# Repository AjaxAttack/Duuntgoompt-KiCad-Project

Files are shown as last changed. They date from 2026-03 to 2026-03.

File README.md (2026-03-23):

# Duuntgoompt-KiCad-Project
## This repo is the Duuntgoompt project files home.
### The Duuntgoompt PCB, with features:
- Esp32s3 based system
- Wifi & Bluetooth compatible
- USB C
- 1x26 Pin M Connections Suitable for breadboard plug-n-use
- Solder Bridge LED Indicators
- Qwiic I2C Connectors for other sensor modules
### Duuntgoompt - Blender Full Render
output gif fuuntboompt

### Duuntgoompt Overhead


### Top-level Schematic Image


### Power Schematic 


### Connectors Schematic


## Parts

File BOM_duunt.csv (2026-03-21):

Id | Designator | Footprint | Quantity | Designation | Supplier and ref
1 | U2 | SOT-89-3 | 1 | AZ1117C
2 | C10,C3,C4,C2,C11,C6,C9,C8,C7 | C_0805_2012Metric | 9 | CL21A226MQQNNNE
3 | R9,R7,R1,R3,R6,R8,R5,R10,R11,R4,R2 | R_0805_2012Metric | 11 | RESISTOR0603
4 | JP2,JP1,JP3 | SolderJumper-2_P1.3mm_Bridged_Pad1.0x1.5mm | 3 | SolderJumper_2_Bridged
5 | R13,R14,R12 | R_0805_2012Metric | 3 | RC0603FR-7W10KL
6 | U1 | ESP32-S3-WROOM-1 | 1 | ESP32-S3-WROOM-1
7 | J2,J1 | PTS526SM08SMTR2LFS | 2 | ~
8 | J3,J6 | 1X04_1MM_RA | 2 | I2C_STANDARDQWIIC
9 | C1 | C_Elec_6.3x7.7 | 1 | RGA221M1EBK-0811G
10 | D3,D2,D1 | LED_0805_2012Metric_Pad1.15x1.40mm_HandSolder | 3 | LED
11 | J7 | TerminalBlock_bornier-2_P5.08mm | 1 | ~
12 | J5 | GCT_USB4520-03-0-A_REVA | 1 | USB4520-03-0-A_REVA
13 | L1 | L_Changjiang_FNR5020S | 1 | SRP3212A-4R7M
14 | U3 | SOT-23-6_Handsoldering | 1 | TPS562208
15 | J8,J4 | PinHeader_1x16_P2.54mm_Vertical | 2 | Conn_01x13_Pin

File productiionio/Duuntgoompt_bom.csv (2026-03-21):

Id | Designator | Footprint | Quantity | Designation | Supplier and ref
1 | U1 | ESP32-S3-WROOM-1 | 1 | ESP32-S3-WROOM-1
2 | U2 | SOT-89-3 | 1 | AZ1117C
3 | C10,C3,C4,C2,C11,C6,C9,C8,C7 | C_0805_2012Metric | 9 | CL21A226MQQNNNE
4 | R9,R7,R1,R3,R6,R8,R5,R10,R11,R4,R2 | R_0805_2012Metric | 11 | RESISTOR0603
5 | JP2,JP1,JP3 | SolderJumper-2_P1.3mm_Bridged_Pad1.0x1.5mm | 3 | SolderJumper_2_Bridged
6 | R13,R14,R12 | R_0805_2012Metric | 3 | RC0603FR-7W10KL
7 | J2,J1 | PTS526SM08SMTR2LFS | 2 | ~
8 | J3,J6 | 1X04_1MM_RA | 2 | I2C_STANDARDQWIIC
9 | C1 | C_Elec_8x10.2 | 1 | RGA221M1EBK-0811G
10 | D3,D2,D1 | LED_0805_2012Metric_Pad1.15x1.40mm_HandSolder | 3 | LED
11 | J7 | xt30 | 1 | ~
12 | J5 | GCT_USB4520-03-0-A_REVA | 1 | USB4520-03-0-A_REVA
13 | L1 | L_Changjiang_FNR5020S | 1 | SRP3212A-4R7M
14 | U3 | SOT-23-6_Handsoldering | 1 | TPS562208
15 | J8,J4 | PinHeader_1x16_P2.54mm_Vertical | 2 | Conn_01x13_Pin

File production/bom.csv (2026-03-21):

Designator | Footprint | Quantity | Value | LCSC Part #
C1 | C_Elec_6.3x7.7 | 1 | RGA221M1EBK-0811G
C10, C11, C2, C3, C4, C6, C7, C8, C9 | 0805 | 9 | CL21A226MQQNNNE
D1, D2, D3 | 0805 | 3 | LED
J1, J2 | PTS526SM08SMTR2LFS | 2 | ~
J3, J6 | 1X04_1MM_RA | 2 | I2C_STANDARDQWIIC
J4, J8 | PinHeader_1x16_P2.54mm_Vertical | 2 | Conn_01x13_Pin
J5 | GCT_USB4520-03-0-A_REVA | 1 | USB4520-03-0-A_REVA
J7 | TerminalBlock_bornier-2_P5.08mm | 1 | ~
JP1, JP2, JP3 | SolderJumper-2_P1.3mm_Bridged_Pad1.0x1.5mm | 3 | SolderJumper_2_Bridged
L1 | L_Changjiang_FNR5020S | 1 | SRP3212A-4R7M
R1, R10, R11, R2, R3, R4, R5, R6, R7, R8, R9 | 0805 | 11 | RESISTOR0603
R12, R13, R14 | 0805 | 3 | RC0603FR-7W10KL
U1 | ESP32-S3-WROOM-1 | 1 | ESP32-S3-WROOM-1
U2 | SOT-89-3 | 1 | AZ1117C
U3 | SOT-23-6_Handsoldering | 1 | TPS562208

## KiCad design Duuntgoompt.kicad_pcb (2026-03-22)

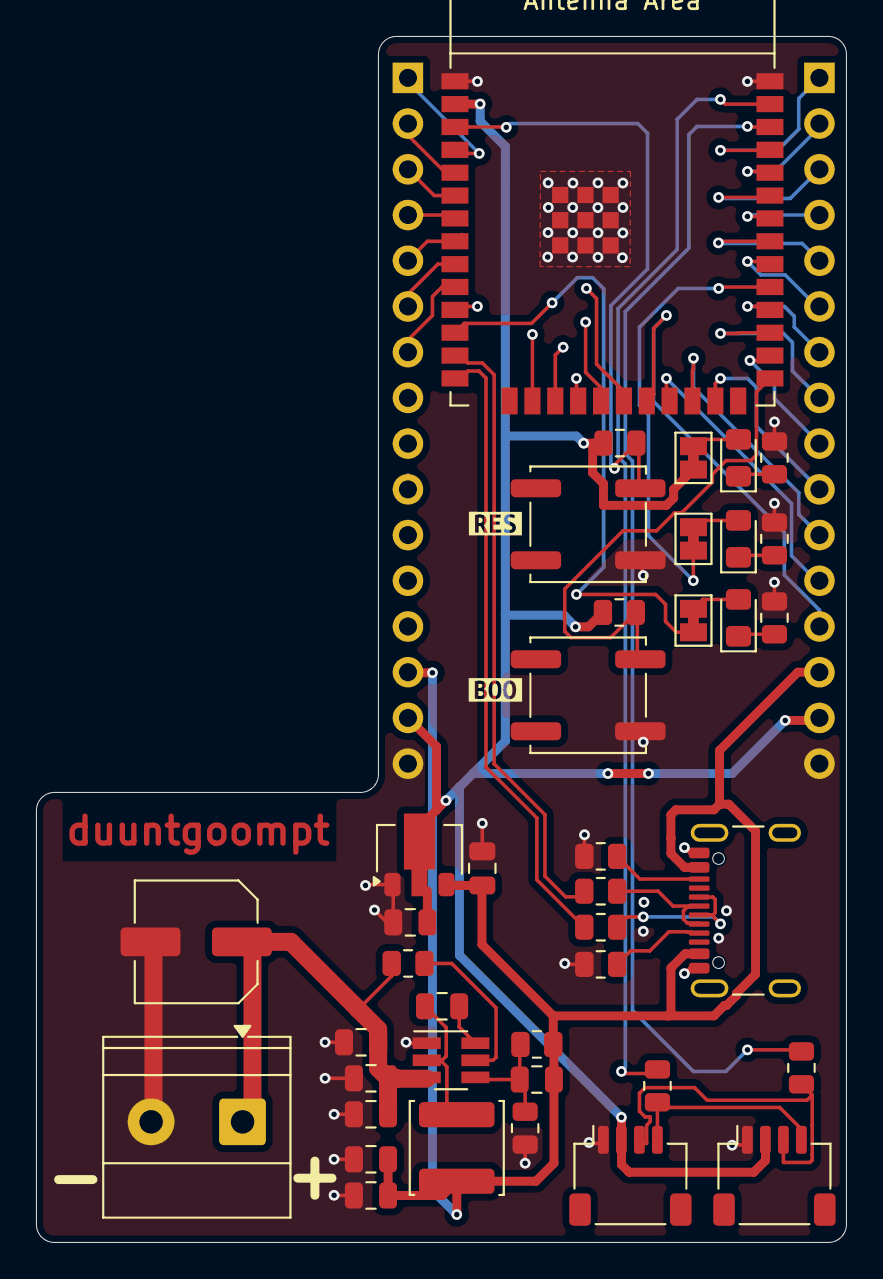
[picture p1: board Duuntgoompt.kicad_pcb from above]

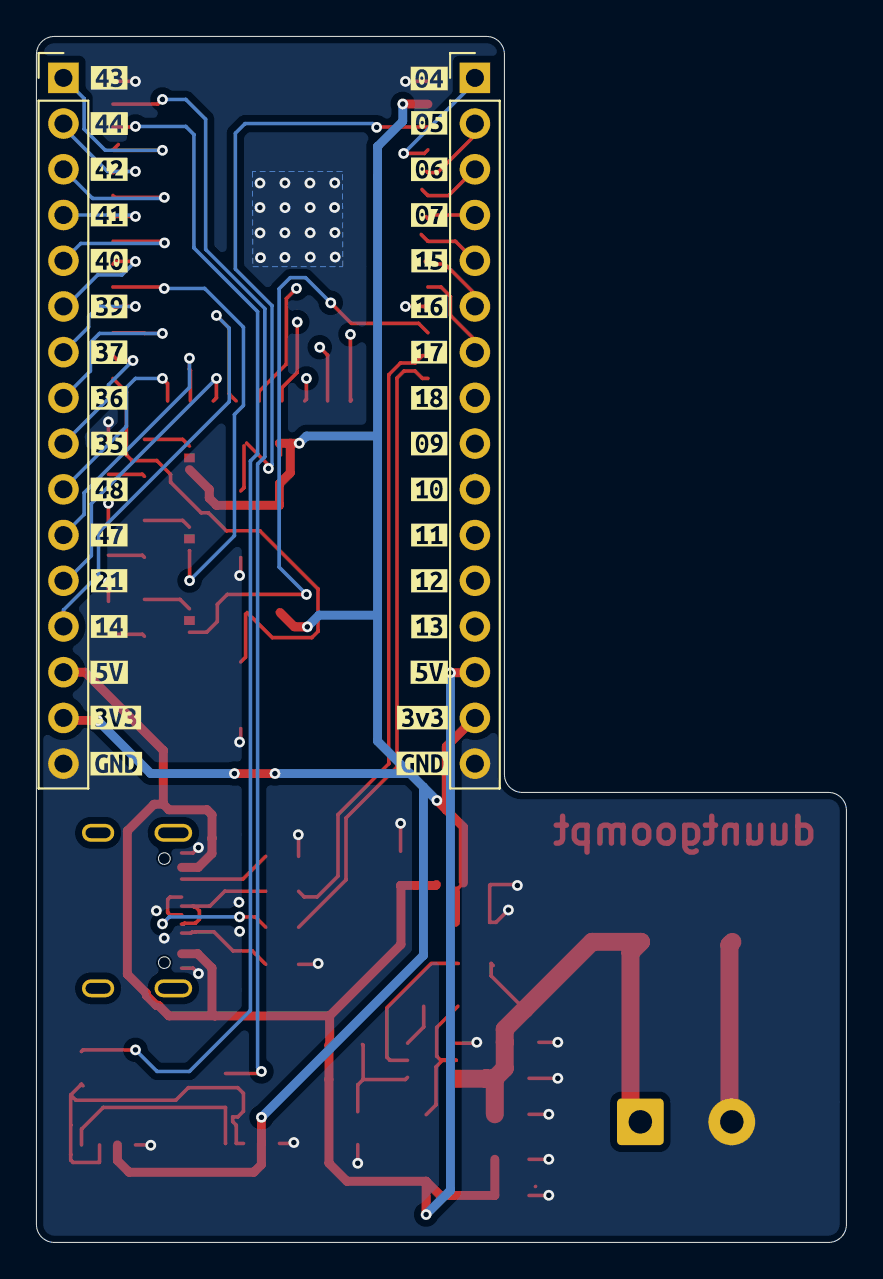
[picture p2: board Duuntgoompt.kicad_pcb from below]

Board: 4 copper layers, 45.0 x 67.0 mm, 76 parts (34 on the bottom side), 54 nets.

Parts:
C1: RGA221M1EBK-0811G; C_Elec_6.3x7.7
C2, C3, C4, C6, C7, C8, C9, C10, C11: CL21A226MQQNNNE; C_0805_2012Metric
D1, D2, D3: LED; LED_0805_2012Metric_Pad1.15x1.40mm_HandSolder
J1, J2: SW_Push_1P1T_NO_CK_KSC7xxJ
J3, J6: I2C_STANDARDQWIIC; JST_SH_SM04B-SRSS-TB_1x04-1MP_P1.00mm_Horizontal
J4, J8: Conn_01x13_Pin; PinHeader_1x16_P2.54mm_Vertical
J5: USB4520-03-0-A_REVA; USB_C_Receptacle_GCT_USB4105-xx-A_16P_TopMnt_Horizontal
J7: TerminalBlock_Phoenix_MKDS-1,5-2-5.08_1x02_P5.08mm_Horizont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
JP1, JP2, JP3: SolderJumper_2_Bridged; SolderJumper-2_P1.3mm_Bridged_Pad1.0x1.5mm
L1: SRP3212A-4R7M; L_Changjiang_FNR5020S
R1, R2, R3, R4, R5, R6, R7, R8, R9, R10, R11: RESISTOR0603; R_0805_2012Metric
R12, R13, R14: RC0603FR-7W10KL; R_0805_2012Metric
U1: ESP32-S3-WROOM-1
U2: AZ1117C; SOT-89-3
U3: TPS562208; SOT-23-6_Handsoldering
kibuzzard-66ABEB3C: G***; kibuzzard-66ABEB3C
kibuzzard-66ABEB4E: G***; kibuzzard-66ABEB4E
kibuzzard-66ABEB5B: G***; kibuzzard-66ABEB5B
kibuzzard-66ABEB61: G***; kibuzzard-66ABEB61
kibuzzard-66ABEB82: G***; kibuzzard-66ABEB82
kibuzzard-66ABEB90: G***; kibuzzard-66ABEB90
kibuzzard-66ABEB98: G***; kibuzzard-66ABEB98
kibuzzard-66ABEBCB: G***; kibuzzard-66ABEBCB
kibuzzard-66ABEBD1: G***; kibuzzard-66ABEBD1
kibuzzard-66ABEBD9: G***; kibuzzard-66ABEBD9
kibuzzard-66ABEBE3: G***; kibuzzard-66ABEBE3
kibuzzard-66ABEBEC: G***; kibuzzard-66ABEBEC
kibuzzard-66ABEC0B: G***; kibuzzard-66ABEC0B
kibuzzard-66ABEC03: G***; kibuzzard-66ABEC03
kibuzzard-66ABEC20: G***; kibuzzard-66ABEC20
kibuzzard-66ABEC54: G***; kibuzzard-66ABEC54
kibuzzard-66ABED0C: G***; kibuzzard-66ABED0C
kibuzzard-66ABED1D: G***; kibuzzard-66ABED1D
kibuzzard-66ABED4A: G***; kibuzzard-66ABED4A
kibuzzard-66ABED5B: G***; kibuzzard-66ABED5B
kibuzzard-66ABED8D: G***; kibuzzard-66ABED8D
kibuzzard-66ABED29: G***; kibuzzard-66ABED29
kibuzzard-66ABED39: G***; kibuzzard-66ABED39
kibuzzard-66ABED41: G***; kibuzzard-66ABED41
kibuzzard-66ABED51: G***; kibuzzard-66ABED51
kibuzzard-66ABED62: G***; kibuzzard-66ABED62
kibuzzard-66ABED69: G***; kibuzzard-66ABED69
kibuzzard-66ABED70: G***; kibuzzard-66ABED70
kibuzzard-66ABED86: G***; kibuzzard-66ABED86
kibuzzard-66ABEDA4: G***; kibuzzard-66ABEDA4
kibuzzard-66ABEDAC: G***; kibuzzard-66ABEDAC
kibuzzard-66ABEDF7: G***; kibuzzard-66ABEDF7
kibuzzard-66ABF63C: G***; kibuzzard-66ABF63C
kibuzzard-66ABF633: G***; kibuzzard-66ABF633

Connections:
+3.3V: C2.1, J3.2 (VCC), J4.15, J6.2 (VCC), J8.15, JP3.1 (A), R1.2, R2.2, U1.2 (3V3), U2.2 (out)
+5V: C3.1, C4.1, C6.1, C7.1, J4.14, J5.A4, J5.B4, J8.14, L1.1, R13.1, U2.3 (in)
+BATT: C1.1 (+), C8.2, C9.2, C10.2, J7.1 (+), R12.2, U3.3 (Vin)
GND: C1.2 (-), C2.2, C3.2, C6.2, C7.2, C8.1, C9.1, C10.1, J1.1, J2.1, J3.1 (GND), J4.16, J5.A1 (GND_A), J5.B1, J6.1 (GND), J7.2 (-), J8.16, R5.1, R6.1, R7.1, R8.2, R9.2, R14.1, U1.1 (GND), U1.40 (GND), U1.41 (GND), U2.1 (adj), U3.1 (GND)
GPIO4: J4.1, U1.4 (GPIO4/TOUCH4/ADC1_CH3)
GPIO5: J4.2, U1.5 (GPIO5/TOUCH5/ADC1_CH4)
GPIO6: J4.3, U1.6 (GPIO6/TOUCH6/ADC1_CH5)
GPIO7: J4.4, U1.7 (GPIO7/TOUCH7/ADC1_CH6)
GPIO8: JP1.1 (A), U1.12 (GPIO8/TOUCH8/ADC1_CH7/SUBSPICS1)
GPIO9: J4.9, U1.17 (GPIO9/TOUCH9/ADC1_CH8/FSPIHD/SUBSPIHD)
GPIO10: J4.10, U1.18 (GPIO10/TOUCH10/ADC1_CH9/FSPICS0/FSPIIO4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)
GPIO11: J4.11, U1.19 (GPIO11/TOUCH11/ADC2_CH0/FSPID/FSPIIO5/S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)
GPIO12: J4.12, U1.20 (GPIO12/TOUCH12/ADC2_CH1/FSPICLK/FSPIIO6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)
GPIO13: J4.13, U1.21 (GPIO13/TOUCH13/ADC2_CH2/FSPIQ/FSPIIO7/S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)
GPIO14: J8.13, U1.22 (GPIO14/TOUCH14/ADC2_CH3/FSPIWP/FSPIDQS/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)
GPIO15: J4.5, U1.8 (GPIO15/U0RTS/ADC2_CH4/XTAL_32K_P)
GPIO16: J4.6, U1.9 (GPIO16/U0CTS/ADC2_CH5/XTAL_32K_N)
GPIO17: J4.7, U1.10 (GPIO17/U1TXD/ADC2_CH6)
GPIO18: J4.8, U1.11 (GPIO18/U1RXD/ADC2_CH7/CLK_OUT3)
GPIO21: J8.12, U1.23 (GPIO21)
GPIO35: J8.9, U1.28 (SPIIO6/GPIO35/FSPID/SUBSPID)
GPIO36: J8.8, U1.29 (SPIIO7/GPIO36/FSPICLK/SUBSPICLK)
GPIO37: J8.7, U1.30 (SPIDQS/GPIO37/FSPIQ/SUBSPIQ)
GPIO38: JP2.1 (A), U1.31 (GPIO38/FSPIWP/SUBSPIWP)
GPIO39: J8.6, U1.32 (MTCK/GPIO39/CLK_OUT3/SUBSPICS1)
GPIO40: J8.5, U1.33 (MTDO/GPIO40/CLK_OUT2)
GPIO41: J8.4, U1.34 (MTDI/GPIO41/CLK_OUT1)
GPIO42: J8.3, U1.35 (MTMS/GPIO42)
GPIO43: J8.1, U1.37 (U0TXD/GPIO43/CLK_OUT1)
GPIO44: J8.2, U1.36 (U0RXD/GPIO44/CLK_OUT2)
GPIO47: J8.11, U1.24 (GPIO47/SPICLK_P/SUBSPICLK_P_DIFF)
GPIO48: J8.10, U1.25 (GPIO48/SPICLK_N/SUBSPICLK_N_DIFF)
unnamed: D1.2 (A), JP1.2 (B)
unnamed: D1.1 (K), R5.2
unnamed: D2.2 (A), JP2.2 (B)
unnamed: D2.1 (K), R6.2
unnamed: D3.2 (A), JP3.2 (B)
unnamed: D3.1 (K), R7.2
unnamed: J3.4 (SCL), J6.4 (SCL), R3.1
unnamed: J3.3 (SDA), J6.3 (SDA), R4.1
unnamed: J5.A5 (CC1), R8.1
unnamed: J5.B5 (CC2), R9.1
unnamed: J5.A7 (DN1), J5.B7 (DN2), R11.1
unnamed: J5.A6 (DP1), J5.B6 (DP2), R10.1
unnamed: J1.2, R1.1, U1.3 (EN)
unnamed: J2.2, R2.1, U1.27 (GPIO0/BOOT)
unnamed: R12.1, U3.5 (EN)
unnamed: C11.1, L1.2, U3.2 (SW)
unnamed: C11.2, U3.6 (VBST)
unnamed: C4.2, R13.2, R14.2, U3.4 (VFB)
scl: R3.2, U1.39 (GPIO1/TOUCH1/ADC1_CH0)
sda: R4.2, U1.38 (GPIO2/TOUCH2/ADC1_CH1)
usb_d+: R10.2, U1.14 (GPIO20/U1CTS/ADC2_CH9/CLK_OUT1/USB_D+)
usb_d-: R11.2, U1.13 (GPIO19/U1RTS/ADC2_CH8/CLK_OUT2/USB_D-)

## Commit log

2026-03-21 initial comment
    [BOM_duunt.csv, DuuntgoomptPCB.kicad_pcb, Duuntgoompt_bom.csv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]
2026-03-22 added some stuff to schematic and PCB design
    [oneOfSuch.kicad_pcb, oneOfSuch.kicad_sch, zinth_connectors.kicad_sch]
2026-03-22 all DRC errors are cleared
    [Duuntgoompt.kicad_pcb, Duuntgoompt.kicad_sch, DuuntgoomptPCB.kicad_pcb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]
